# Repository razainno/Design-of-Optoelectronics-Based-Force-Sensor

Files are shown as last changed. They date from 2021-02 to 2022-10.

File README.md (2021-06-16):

 
 # Force-sensor Design 

The following step for the design of the sensor has been completed.
      
 ## 1. Mechanical design of sensor prototype has been done in solid work with following component and printed
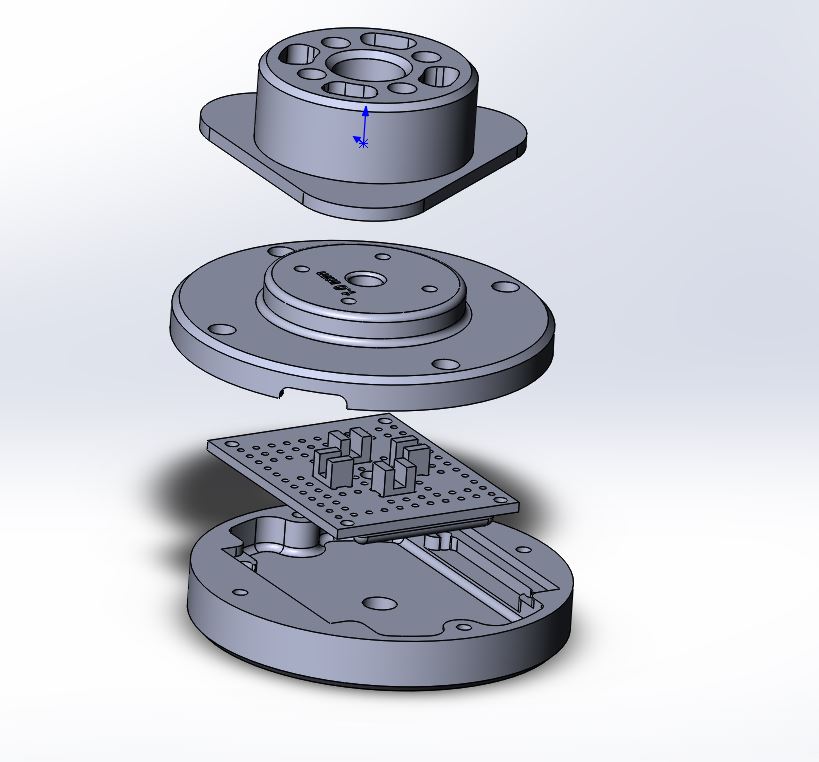
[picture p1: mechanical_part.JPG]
  

   ## 2. electrical protype using four opto sensor is the following
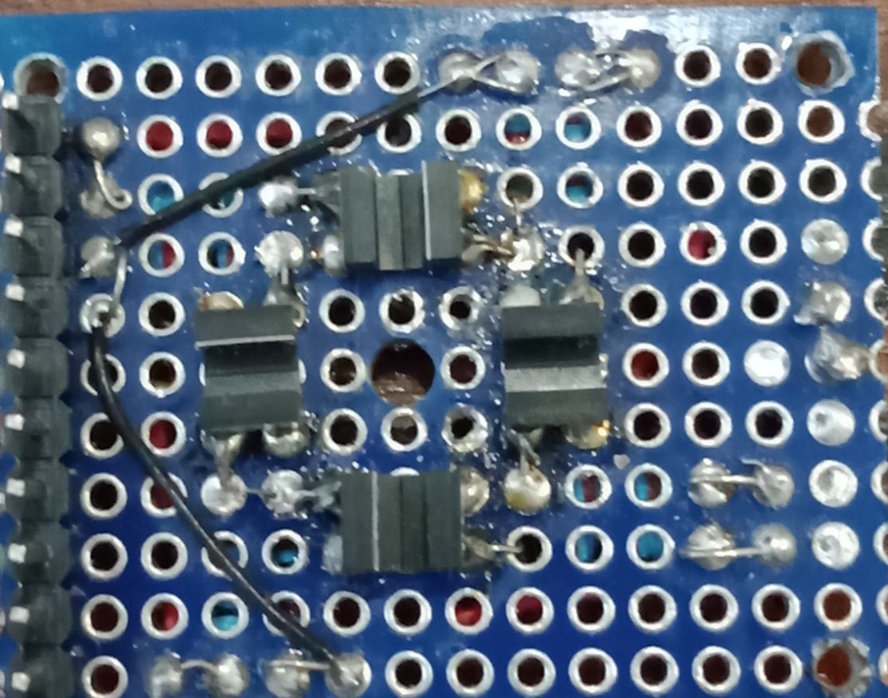
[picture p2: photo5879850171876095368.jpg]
 3. 

 ## 3. Raw data reading
 When obstacle inturrupt the path of from four sensors and voltage decreased, these vlaue with help of Adc has been converted into digital value and feed into raspberry pi for process where we can read the Raw data

 ## 4. Save the data for different weight (0kg ,0.5kg, 1.25kg, 1.75kg
Different value of the weight has been put n the sensor and value for the voltage has been save for all four sensors
 ## 5. Calculation of the weights for using least square method 
 AS we now that at statring point the there is no value for the sensor voltage because no for force has been applied 
 form equation F=V1xw1+V2xw2+V3xw3+V4xw4, the weight(w1,w2,w3,w4) has been calculated using least square method 
 ##  6. Calculation of the force using above calculated weights
 after callculation of the weight of the force can been calculated with  eqaution F=V1xw1+V2xw2+V3xw3+V4xw4 
  ## 7. Test the sensor for applying different force
 Applying random force and following result for calibrated sensor has been produced.
 
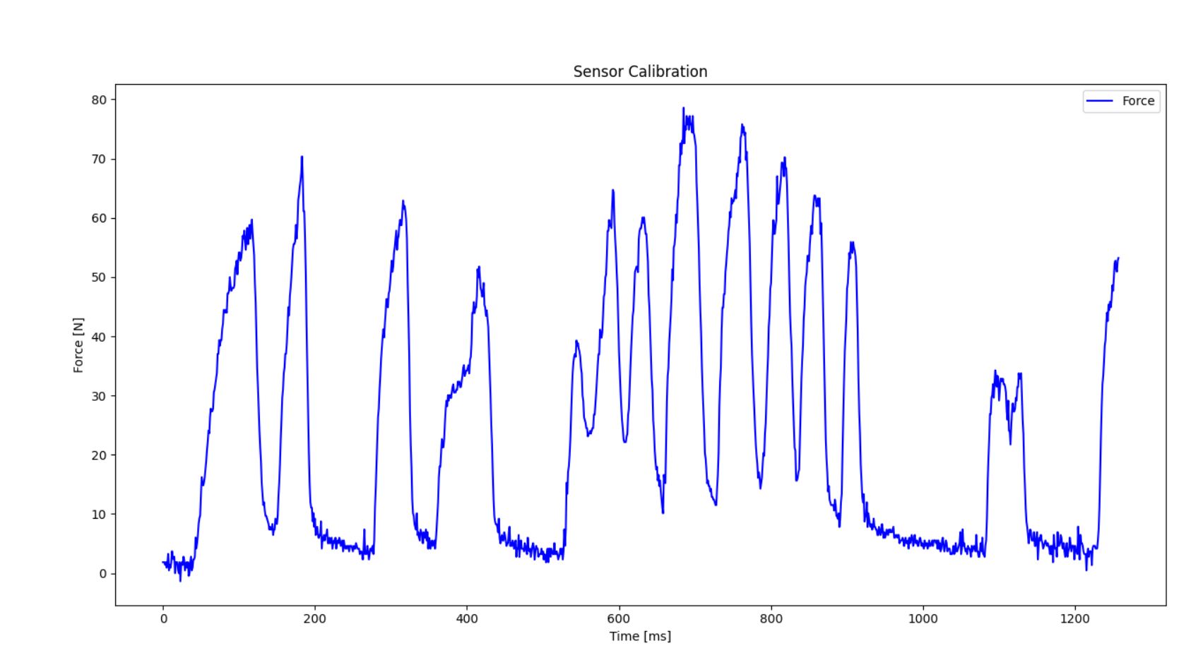
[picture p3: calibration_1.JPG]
  
  ## 8. PCB Board design
  The whole design is created in Altium designer output can be seen below in images
  <p float="left">
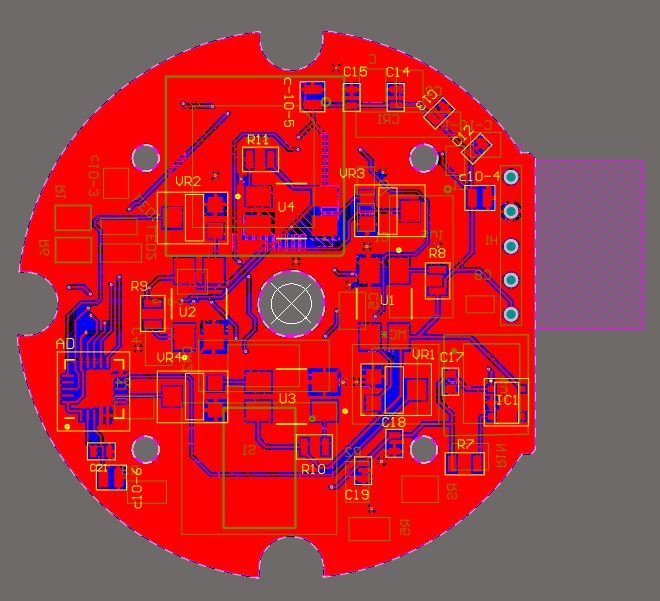
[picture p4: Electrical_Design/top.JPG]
  
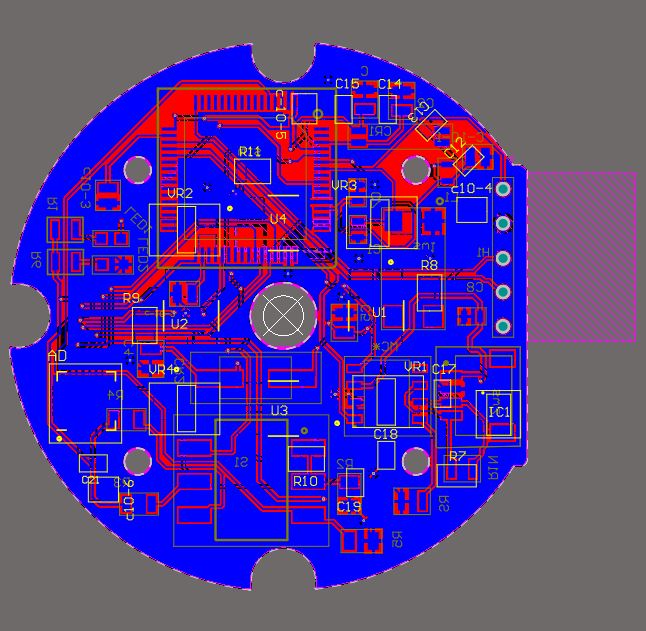
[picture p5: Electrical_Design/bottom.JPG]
   
</p>
 The 3d View of the pscb board is shown below
 <p float="left">
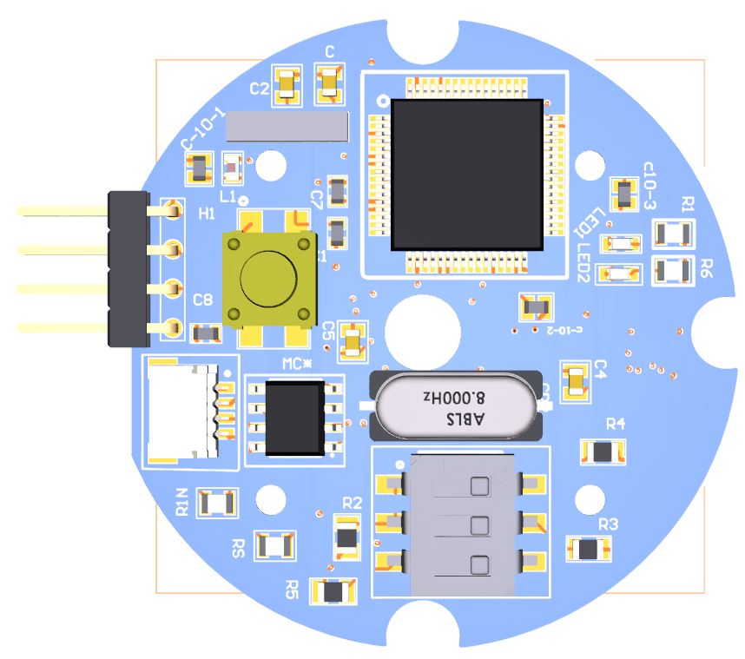
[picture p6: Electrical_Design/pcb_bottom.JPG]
  
   
</p>

 ## 8. Calibation results and comparison with Futek sensor
 Results are shown in following figure:
 
 </p>
 
 <p float="left">
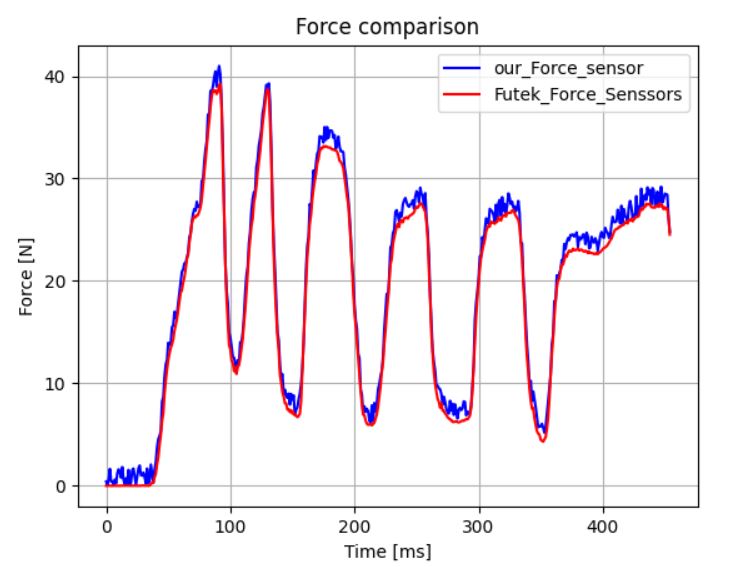
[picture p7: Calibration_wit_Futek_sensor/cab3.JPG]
  
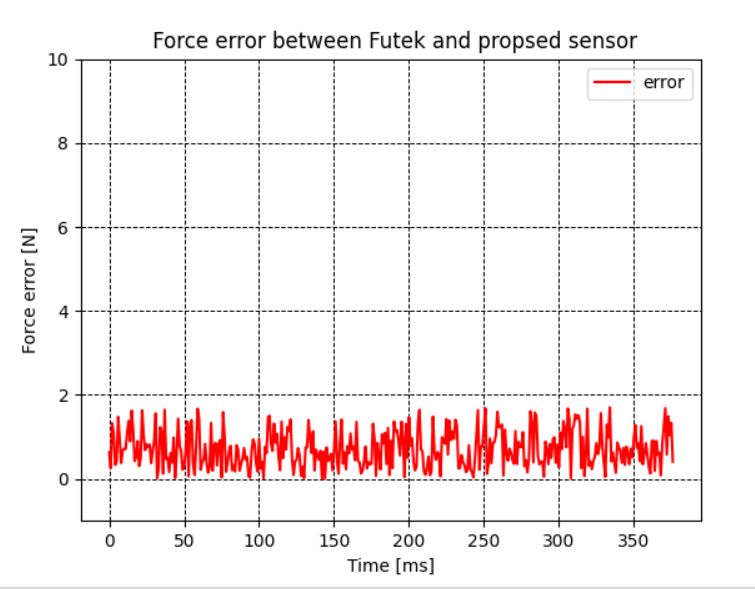
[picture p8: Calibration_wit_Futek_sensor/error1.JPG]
   
</p>
 Second experiment
 </p>
 <p float="left">
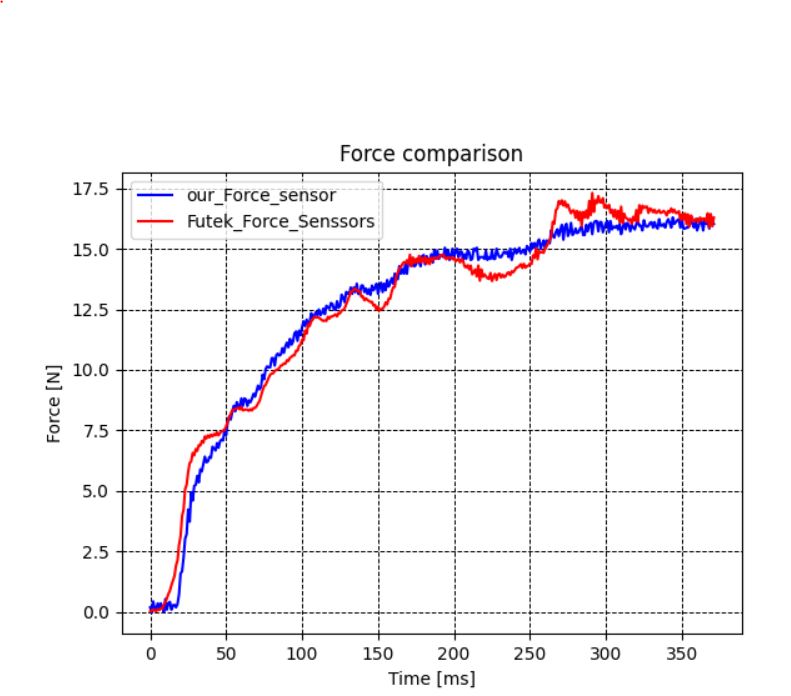
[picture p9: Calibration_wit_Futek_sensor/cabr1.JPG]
  
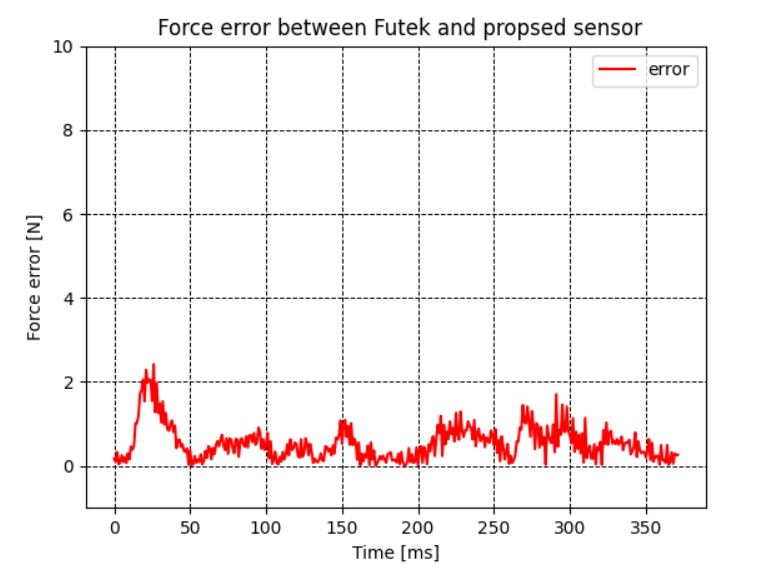
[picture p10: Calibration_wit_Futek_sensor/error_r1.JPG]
   
</p>

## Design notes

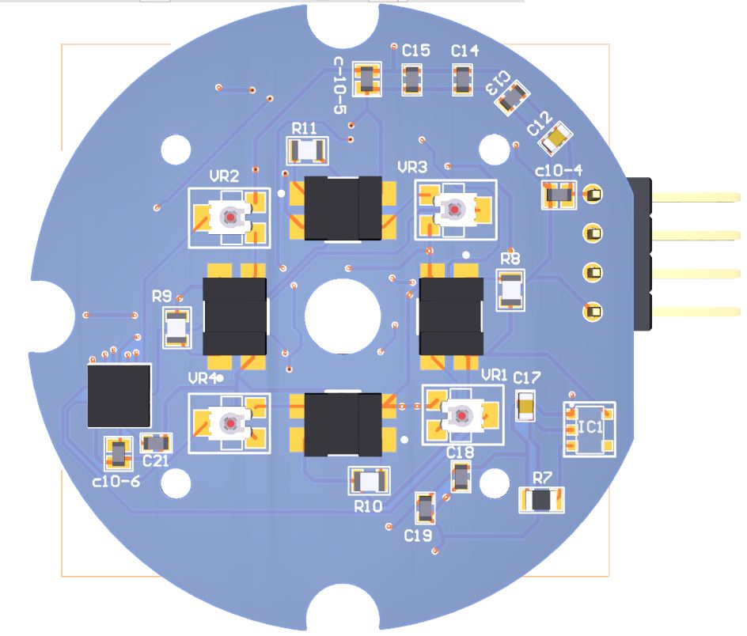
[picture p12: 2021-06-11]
Electrical_Design/pcb_top.JPG

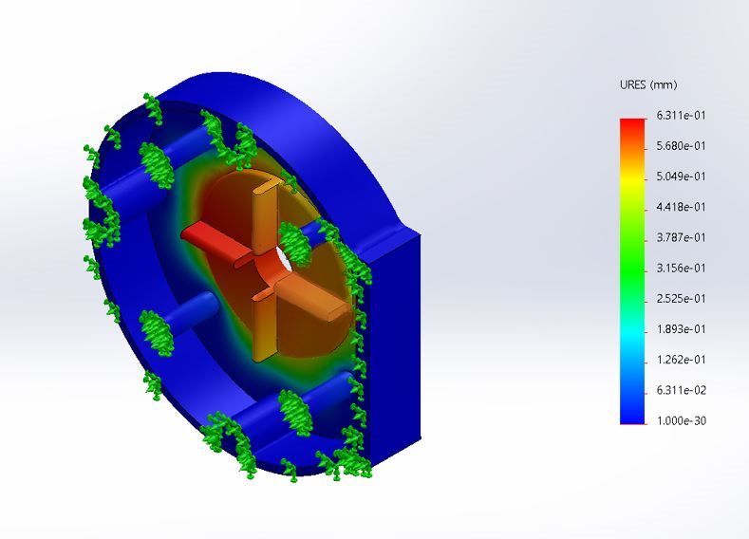
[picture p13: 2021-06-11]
Mechanical_Design/fea1.png

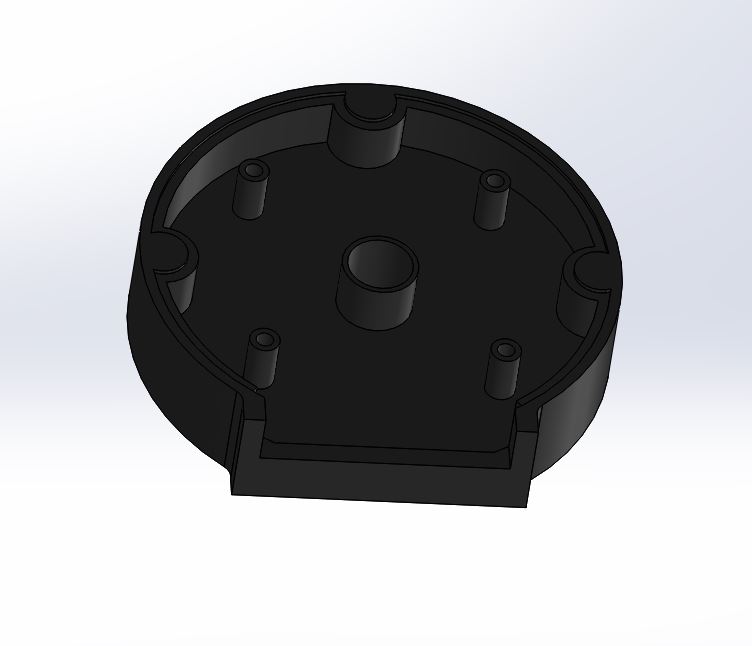
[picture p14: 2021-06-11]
Mechanical_Design/base12.JPG

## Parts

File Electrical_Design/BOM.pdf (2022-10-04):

Designator | Footprint | Description | Comment | Manufacturer Part Number Quantity
[NoValue], stm | Quad64 | STMICROELECTRONICS - STM32F405RGT7 - ARM MCU, Advanced Connectivity and Encryption, STM32 Family STM32F4 Series Microcontrollers STM32F405RGT7 | | STM32F405RGT7 | 2
AD | CP-20-4_M | IC ADC 16BIT 4CH 250KSPS 20LFCSP AD7682BCPZRL7 | | AD7682BCPZRL7 | 1
C1, C7, C8, C13, C14, C15, C18, C19, C21 cap_100nf | | 0603 0.1 uF 16 V ±10% Tolerance X7R SMT Multilayer Ceramic Chip Capacitor 0.1uf | | VJ0603Y104KXJCW1BC | 9
C12, C17 | Cap-1uf | TAIYO YUDEN - TMK107B7105KA-T - SMD Multilayer Ceramic Capacitor, 1 µF, 25 V, 0603 [1608 Metric], ± 10%, X7R, M Series 1uf | | TMK107B7105KA-T | 2
C, C2, C4, C5 | Cap-22uf | CAP CER 22PF 10V C0G/NP0 0805 22pf | | C0805C220J8GAC7800 | 4
cap1, cap2, cap3, cap4, cap5, cap6 Cap-10 | | CAP 10UF 10V X7R 20% SMD 0805 10uf | | C0805C106M8RACTU | 6
CR1 | crytal | Crystal 0.032768MHz 7pF 4-Pin SMD T/R SSPT7F-7PF20-R | | SSPT7F-7PF20-R | 1
CR2 | crystal-12mhz | Crystal 12MHz ±20ppm (Tol) ±50ppm (Stability) 18pF FUND 60Ohm 2-Pin HC-49/US SMD T/R 12Mhz | | ABLS7M-12.000MHZ-B-2-T | 1
H1 | connector | WURTH ELEKTRONIK - 61300511021 - Board-To-Board Connector, 2.54 mm, 5 Contacts, Header, WR-PHD Series, Through Hole, 1 Rows 61300511021 | | 61300511021 | 1
IC1 | FT9013 | RICHTEK RT9013-12GB IC, LDO, FIXED, 1.2V, 0.5A, SOT-23-5 RT9013-12GB | | RT9013-12GB | 1
L1 | inductor | Fixed Inductors 4700nH, 15mA Tol.=+/-5% 4.7uH | | AIML-0603-4R7K-T | 1
LED1 | LED-Green | LED GREEN DIFFUSED 0603 SMD geen | | LT Q39G-Q1OO-25-1 | 1
LED2 | LED-RED | LED RED CLEAR CHIP SMD RED | | APT1608SRCPRV | 1
MC* | mcp2551 | CAN Interface IC Hi Spd CAN Transceiv MCP2551T-I/SN | | MCP2551T-I/SN | 1
R1, R6 | Resistor-510 | Res Thick Film 0805 510 Ohm 1% 0.125W(1/8W) ±100ppm/C Epoxy Pad SMD T/R 510 | | RC0805FR-07510RL | 2
R1N | res-1k | RES SMD 120 OHM 0.02% 1/10W 0805 120 | | Y1629120R000Q9R | 1
R2, R5 | Resistor-10k | MCU 0805-25 0.1% AT P1 10K 10k | | MCU0805MD1002BP100 | 2
R3, R4, R7 | Resistor-smd-4.7k | TR / Thin Film Chip Resistors 0805 0.1W 4.7Kohm 0.01% 2ppm 4.7k | | RG2012L-472-L-T05 | 3
R8, R9, R10, R11 | Resistor-390 | RES SMD 390 OHM 1% 1/8W 0805 390 Ohms | | | 4
RS | res-1k | RES SMD 1K OHM 0.01% 1/10W 0805 1k | | RG2012L-102-L-T05 | 1
S1 | DIP6 | Switch DIP ON OFF SPST 3 Flush Slide 0.1A 20VDC Gull Wing 2.54mm SMD T/R 219-3LPSTR | | 219-3LPSTR | 1
sw1 | switch | E-SWITCH - TL3305AF160QG - TACTILE SW, SPST, 0.05A, 12VDC, SOLDER TL3305AF160QG | | TL3305AF160QG | 1
sw2 | JST_SM04B-SRSS-TB(LF)(SN) JST (JAPAN SOLDERLESS TERMINALS) - SM04B-SRSS-TB(LF)(SN) - Wire-To-Board Connector, 1 mm, 4 Contacts, Header, SH Series, Surface Mount, 1 Rows SM04B-SRSS-TB(LF)(SN) SM04B-SRSS-TB(LF)(SN) | | | | 1
U1, U2, U3, U4 | Omron_EE-SX1108_0 | | EE-SX1108 | | 4
VR1, VR2, VR3, VR4 | variable-resistor | Res Trimmer 10K Ohm 25% 1/10W 1(Elec)/1(Mech)Turn (3 X | | TC33X-2-103E | 3.8mm) Foot Print SMD Embossed T/R 10k 4

Total Price
Calculation for
electronic
component | 25$
Mechanical design
Using CNC Machine | 5$

Total Price of
Composed sensor | 30$

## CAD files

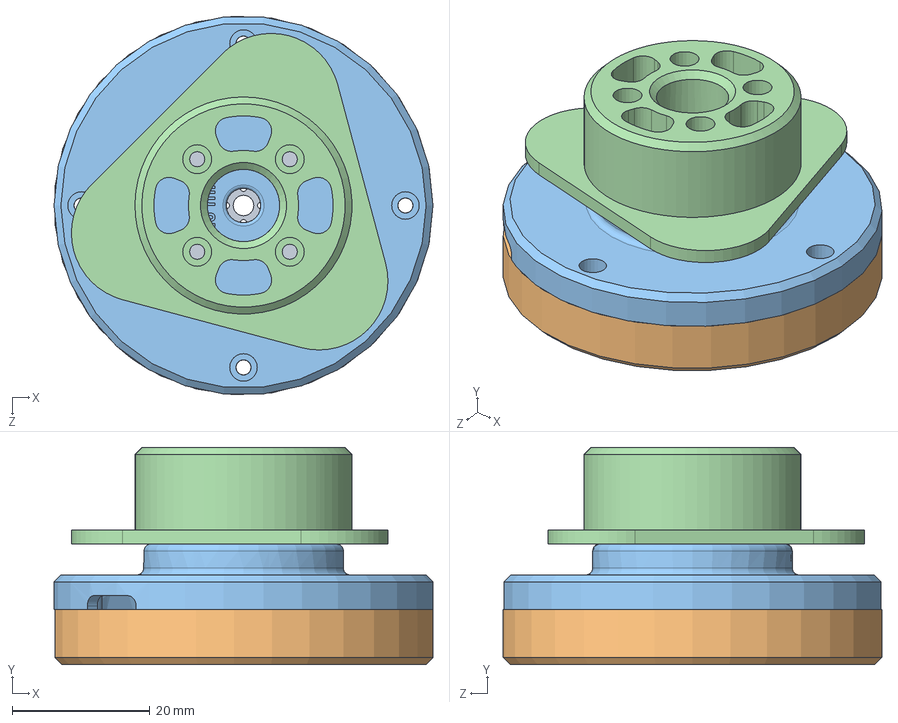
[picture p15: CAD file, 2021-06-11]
Mechanical_Design/Prototype_design/FS_assy.SLDASM
55.0 x 31.5 x 54.9 mm
Force_sensor_v1
FS_holder
FS_cap

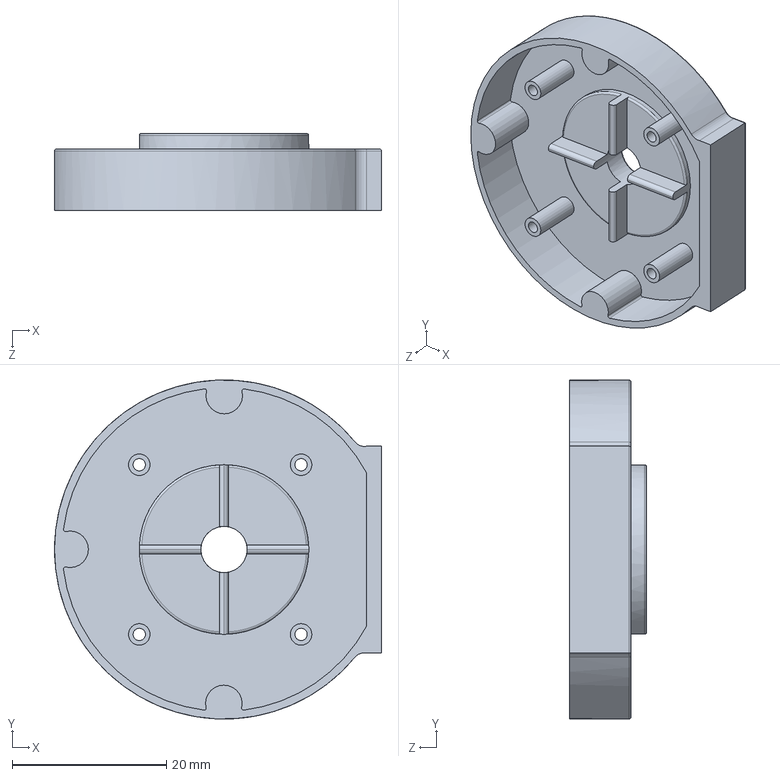
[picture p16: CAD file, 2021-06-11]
Mechanical_Design/Design_final/cap_sensor.SLDPRT
42.4 x 44.0 x 10.0 mm

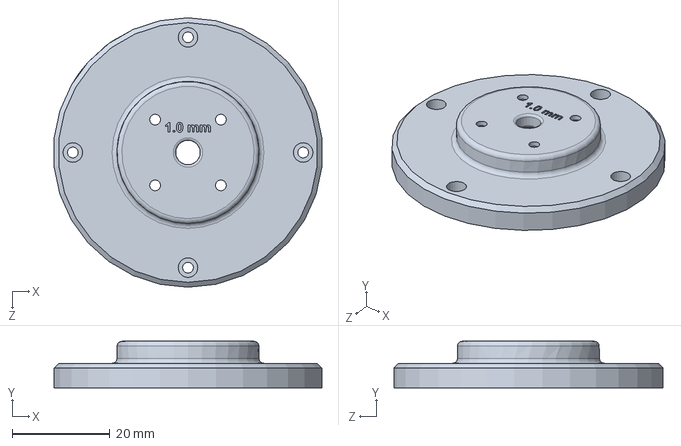
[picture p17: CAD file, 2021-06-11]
Mechanical_Design/Prototype_design/FS_cap.SLDPRT
54.7 x 9.50 x 55.0 mm

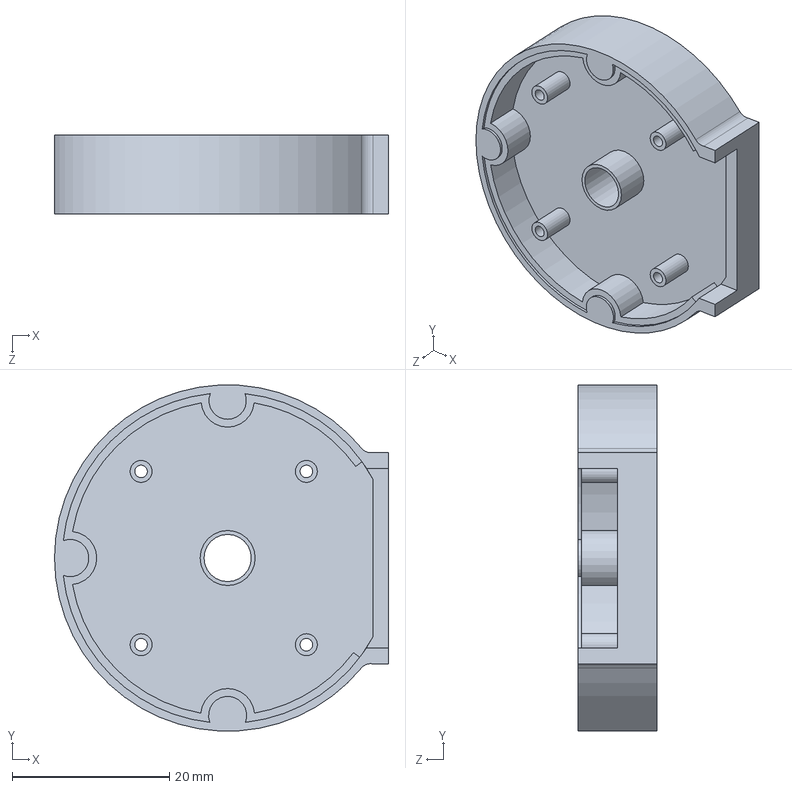
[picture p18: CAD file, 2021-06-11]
Mechanical_Design/Design_final/base_sensor.SLDPRT
42.4 x 43.9 x 10.0 mm

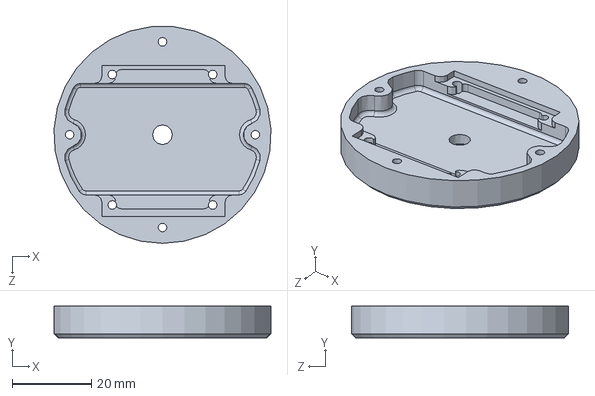
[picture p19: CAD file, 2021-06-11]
Mechanical_Design/Prototype_design/FS_holder.SLDPRT
54.9 x 8.00 x 54.9 mm

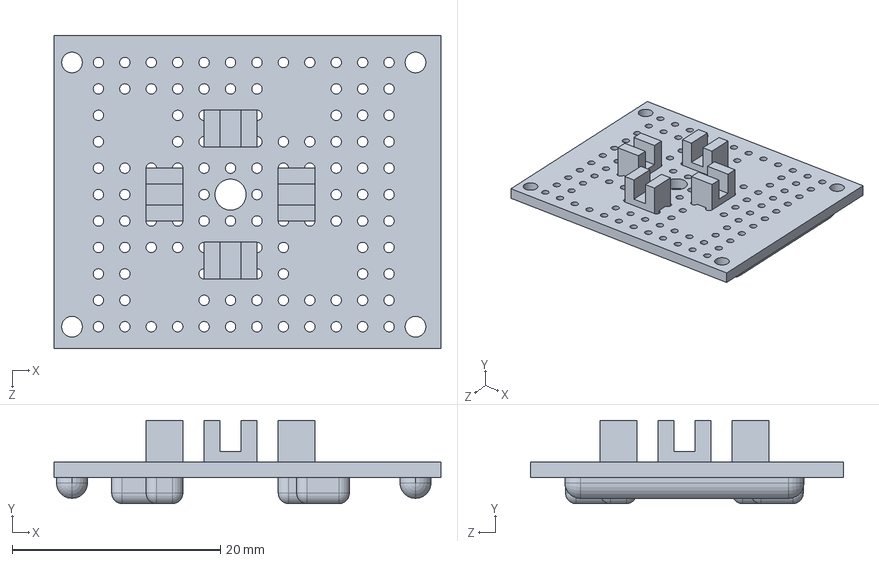
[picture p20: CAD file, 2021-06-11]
Mechanical_Design/Prototype_design/Force_sensor_v1.SLDPRT
37.2 x 8.00 x 30.1 mm

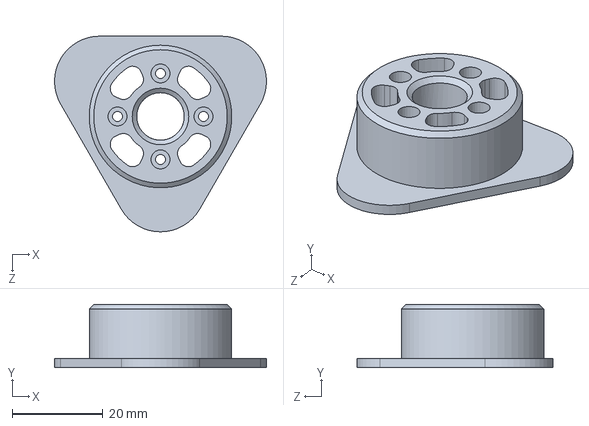
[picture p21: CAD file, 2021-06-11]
Mechanical_Design/Prototype_design/Load_connector.SLDPRT
46.8 x 14.0 x 43.2 mm

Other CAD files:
Mechanical_Design/Prototype_design/Print files/FS_cap_10.STL
Mechanical_Design/Prototype_design/Print files/FS_cap_07.STL
Mechanical_Design/Prototype_design/System_parameters.SLDPRT
Mechanical_Design/Prototype_design/Print files/FS_holder.STL
Mechanical_Design/Prototype_design/Print files/Load_connector.STL

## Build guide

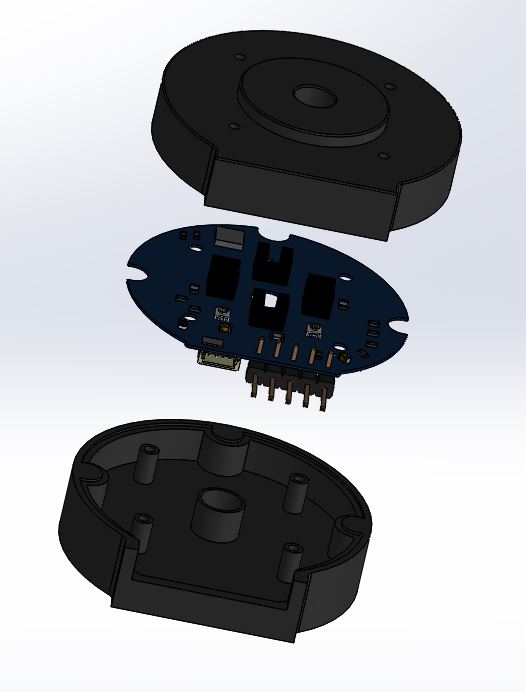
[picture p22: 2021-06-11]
Mechanical_Design/assemblly.JPG

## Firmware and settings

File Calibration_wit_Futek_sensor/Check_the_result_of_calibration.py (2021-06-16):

# -*- coding: utf-8 -*-
"""
Created on Fri Jun 11 13:40:58 2021

@author: Muhammad Ilyas Raza
"""

import numpy as np
import csv
import time
import matplotlib.pyplot as plt
import board
import busio
import adafruit_ads1x15.ads1115 as ADS
from adafruit_ads1x15.analog_in import AnalogIn
i2c=busio.I2C(board.SCL,board.SDA)
ads=ADS.ADS1115(i2c)
print('Reading ADS1x15 values, press Ctrl-C to quit...')
# Print nice channel column headers.
print('| {0:>6} | {1:>6} | {2:>6} | {3:>6} |'.format(*range(4)))
print('-' * 37)

channels = {}
offsets = {}

Force1=[]
Force2=[]
Error=[]
timeout = time.time() + 2*10  # 5 minutes from now

for channel in range(4):
    offsets[channel+1] = AnalogIn(ads,channel).value

    

while True:
    #f=open('data1.75_nkg.csv','a',newline="")
    #file=csv.writer(f)
    if time.time() > timeout:
        break
    
    for channel in range(4):
        channels[channel+1] = AnalogIn(ads,channel).value - offsets[channel+1]
    time.sleep(0.005)
    #F= channels[2]*(-0.49245174)+channels[3]*(1.03675718)+channels[4]*(-0.52497244)
    
    print(f'{channels[1]} | {channels[2]} | {channels[3]} | {channels[4]}|')
    F1=  channels[2]*(-0.004332)+ channels[3]*(0.003211)+channels[4]*( -0.039085)
    F2=channels[1]*(0.0145)
    Force1.append(F1)
    Force2.append(F2)
    error=F2-F1
    if error < 0:
        error=error*(-1)
    Error.append(error)
    print(F1 ,"N")
    print(F2, "N")
    


plt.plot(Force1, color='b', label="our_Force_sensor")
plt.plot(Force2, color='r', label="Futek_Force_Senssors")
plt.title("Force comparison")
plt.xlabel("Time [ms]")
plt.ylabel("Force [N]")
plt.legend(loc='best')

plt.grid(color = 'black', linestyle = '--', linewidth = 0.7)
plt.show()

#Error graph
plt.plot(Error, color='r', label="error")

plt.title(" Force error between Futek and propsed sensor")
plt.xlabel("Time [ms]")
plt.ylabel("Force error [N]")
plt.ylim(-1,10)
plt.legend(loc='best')

plt.grid(color = 'black', linestyle = '--', linewidth = 0.7)
plt.show()

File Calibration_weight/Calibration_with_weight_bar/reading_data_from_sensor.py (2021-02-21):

import time
import board
import busio
import adafruit_ads1x15.ads1115 as ADS
from adafruit_ads1x15.analog_in import AnalogIn
i2c=busio.I2C(board.SCL,board.SDA)
ads=ADS.ADS1115(i2c)
print('Reading ADS1x15 values, press Ctrl-C to quit...')
# Print nice channel column headers.
print('| {0:>6} | {1:>6} | {2:>6} | {3:>6} |'.format(*range(4)))
print('-' * 37)

channels = {} 
offsets = {}
for channel in range(3):
    offsets[channel+1] = AnalogIn(ads,channel).value
    

while True:
    
    for channel in range(3):
        channels[channel+1] = AnalogIn(ads,channel).value - offsets[channel+1]

   # channel0=AnalogIn(ads,0)
    #channel1=AnalogIn(ads,1)
    #channel2=AnalogIn(ads,2)
    #channel3=AnalogIn(ads,3)
    print(f'{channels[1]} | {channels[2]} | {channels[3]} |')
    #print("{:>5}\t{:>5}".format(channel0.value,channel0.voltage))
    #print('| {0:>6} | {1:>6} | {2:>6} | {3:>6} |'.format(channel0.value,channel1.value,channel2.value,channel3.value,))
    # Pause for half a second.
    time.sleep(1)
